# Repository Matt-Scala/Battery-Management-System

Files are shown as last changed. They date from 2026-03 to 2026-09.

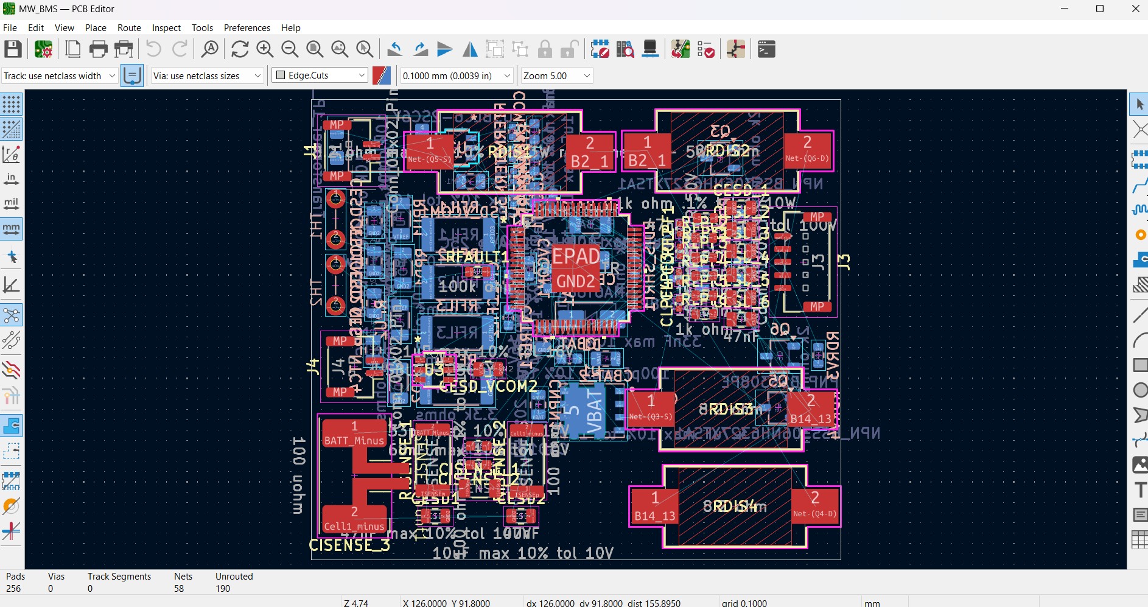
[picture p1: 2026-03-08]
BMS_layout_picture.jpg

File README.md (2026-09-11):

## Members
Matthew Scala, Electrical Engineering
matthewscala3820@vt.edu 

## Mentor
Shane Wyman

## Current Status
Finished

## Project Overview
Create a 4-layer PCB BMS(Battery Management System) with voltage, current, temperature, and fault monitoring. Also, include active cell balancing.

## Educational Value Added

Batteries
Analog routing
SPI communication
Embedded systems
PCB Design 
Electronic Circuit Design

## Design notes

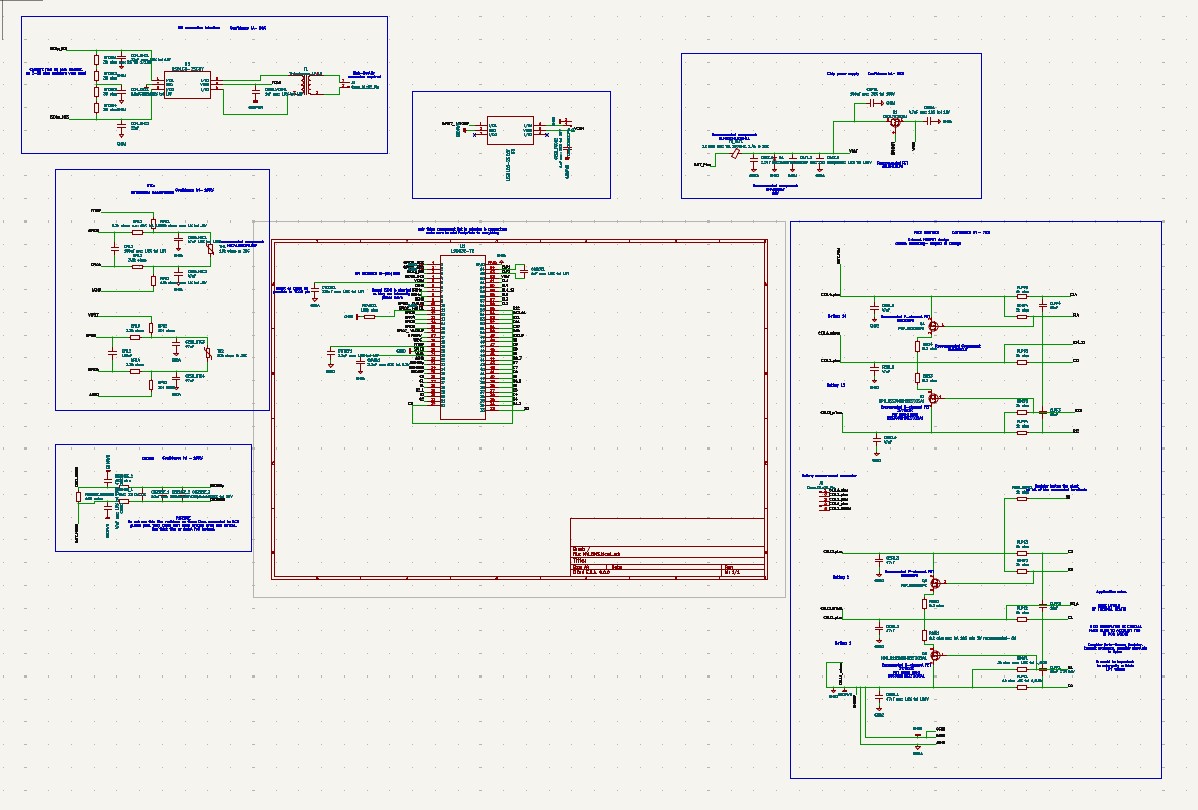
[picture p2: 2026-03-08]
BMS_schematic_picture.jpg

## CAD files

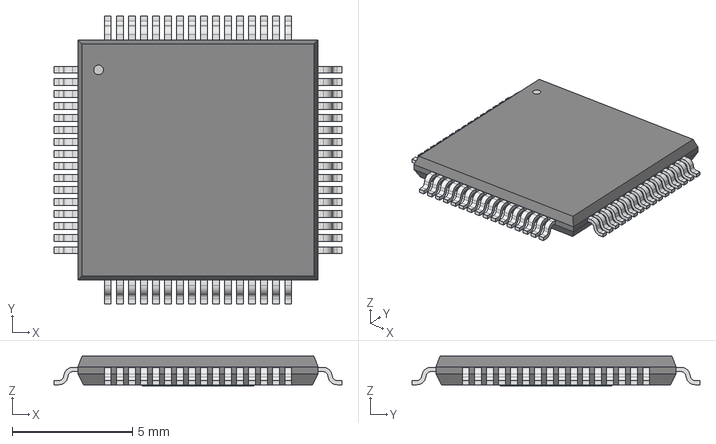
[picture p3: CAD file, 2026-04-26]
CAD_L9963E_TR/TQFP_63E-TR_STM.step
12.0 x 12.0 x 1.25 mm

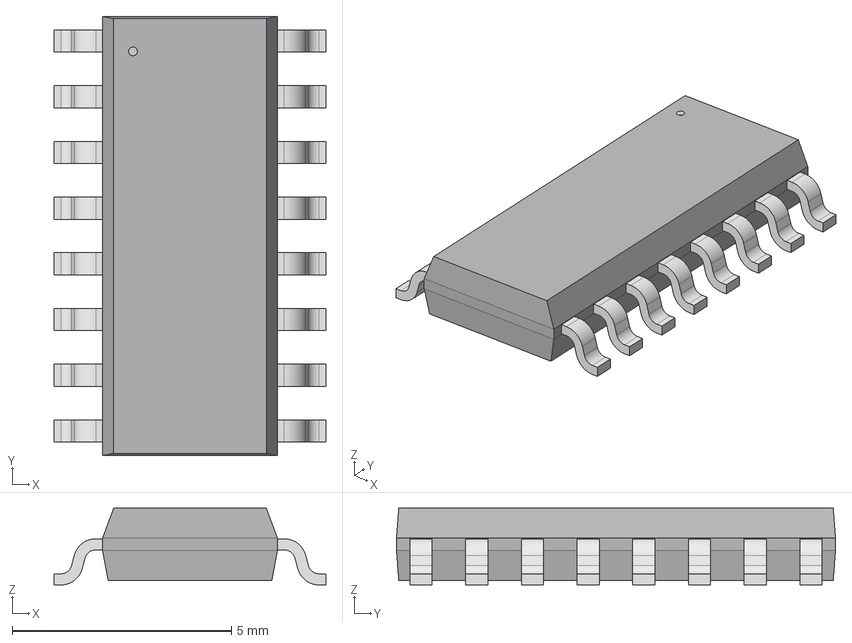
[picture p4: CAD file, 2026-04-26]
CAD_L9963T_TR/SO16N_4X10X1P27_STM.step
6.20 x 10.0 x 1.75 mm

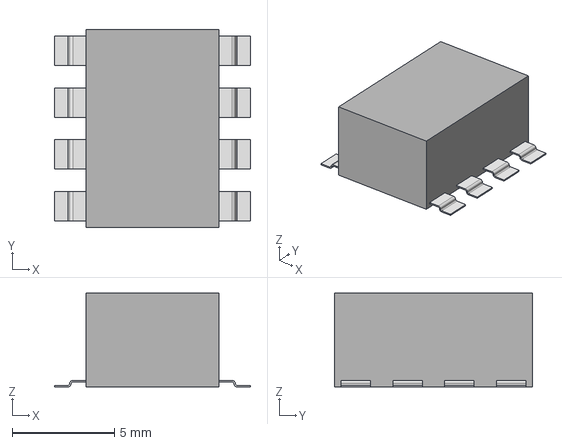
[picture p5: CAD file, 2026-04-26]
CAD_LTV_827S_TA1/LVT-827S_LTO.step
9.60 x 9.68 x 4.60 mm

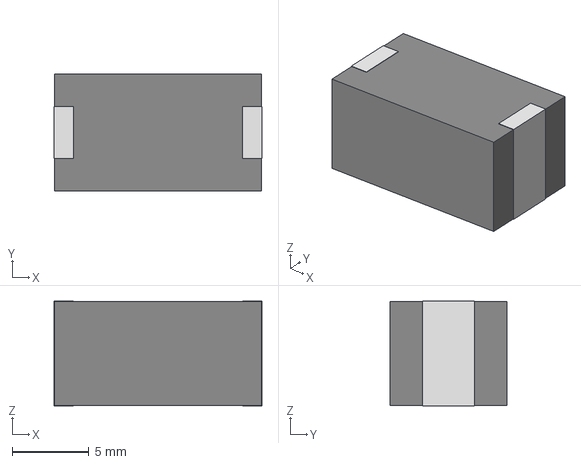
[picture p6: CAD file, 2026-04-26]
CAD_SMW58R2JT/RES_SMF5_TYCO_TYC.step
13.5 x 7.59 x 6.81 mm

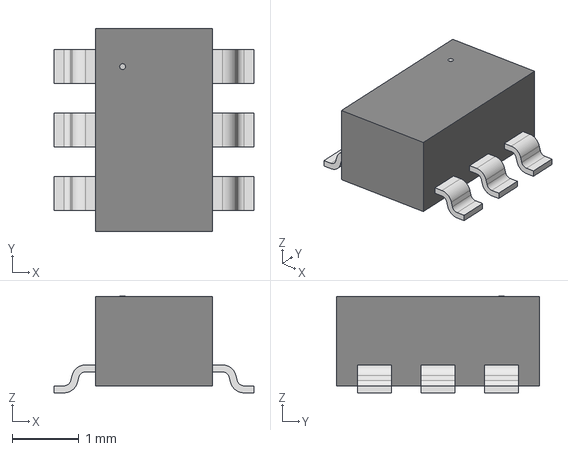
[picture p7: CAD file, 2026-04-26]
CAD_USBLC6_2SC6Y/SOT23-6L_STM.step
3.00 x 3.05 x 1.45 mm

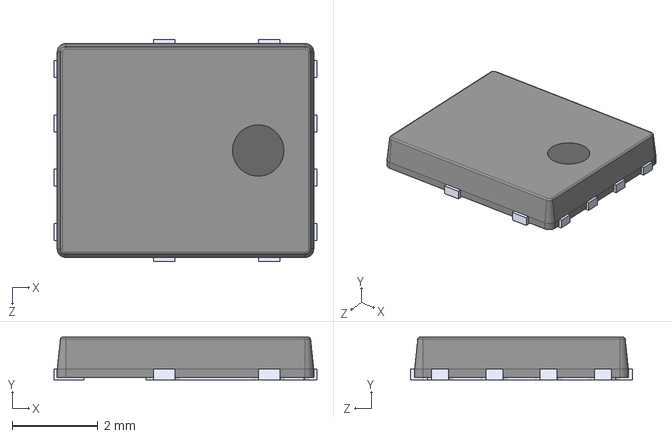
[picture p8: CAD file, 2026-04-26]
STL8N10LF3/STL8N10LF3.step
6.15 x 1.00 x 5.20 mm

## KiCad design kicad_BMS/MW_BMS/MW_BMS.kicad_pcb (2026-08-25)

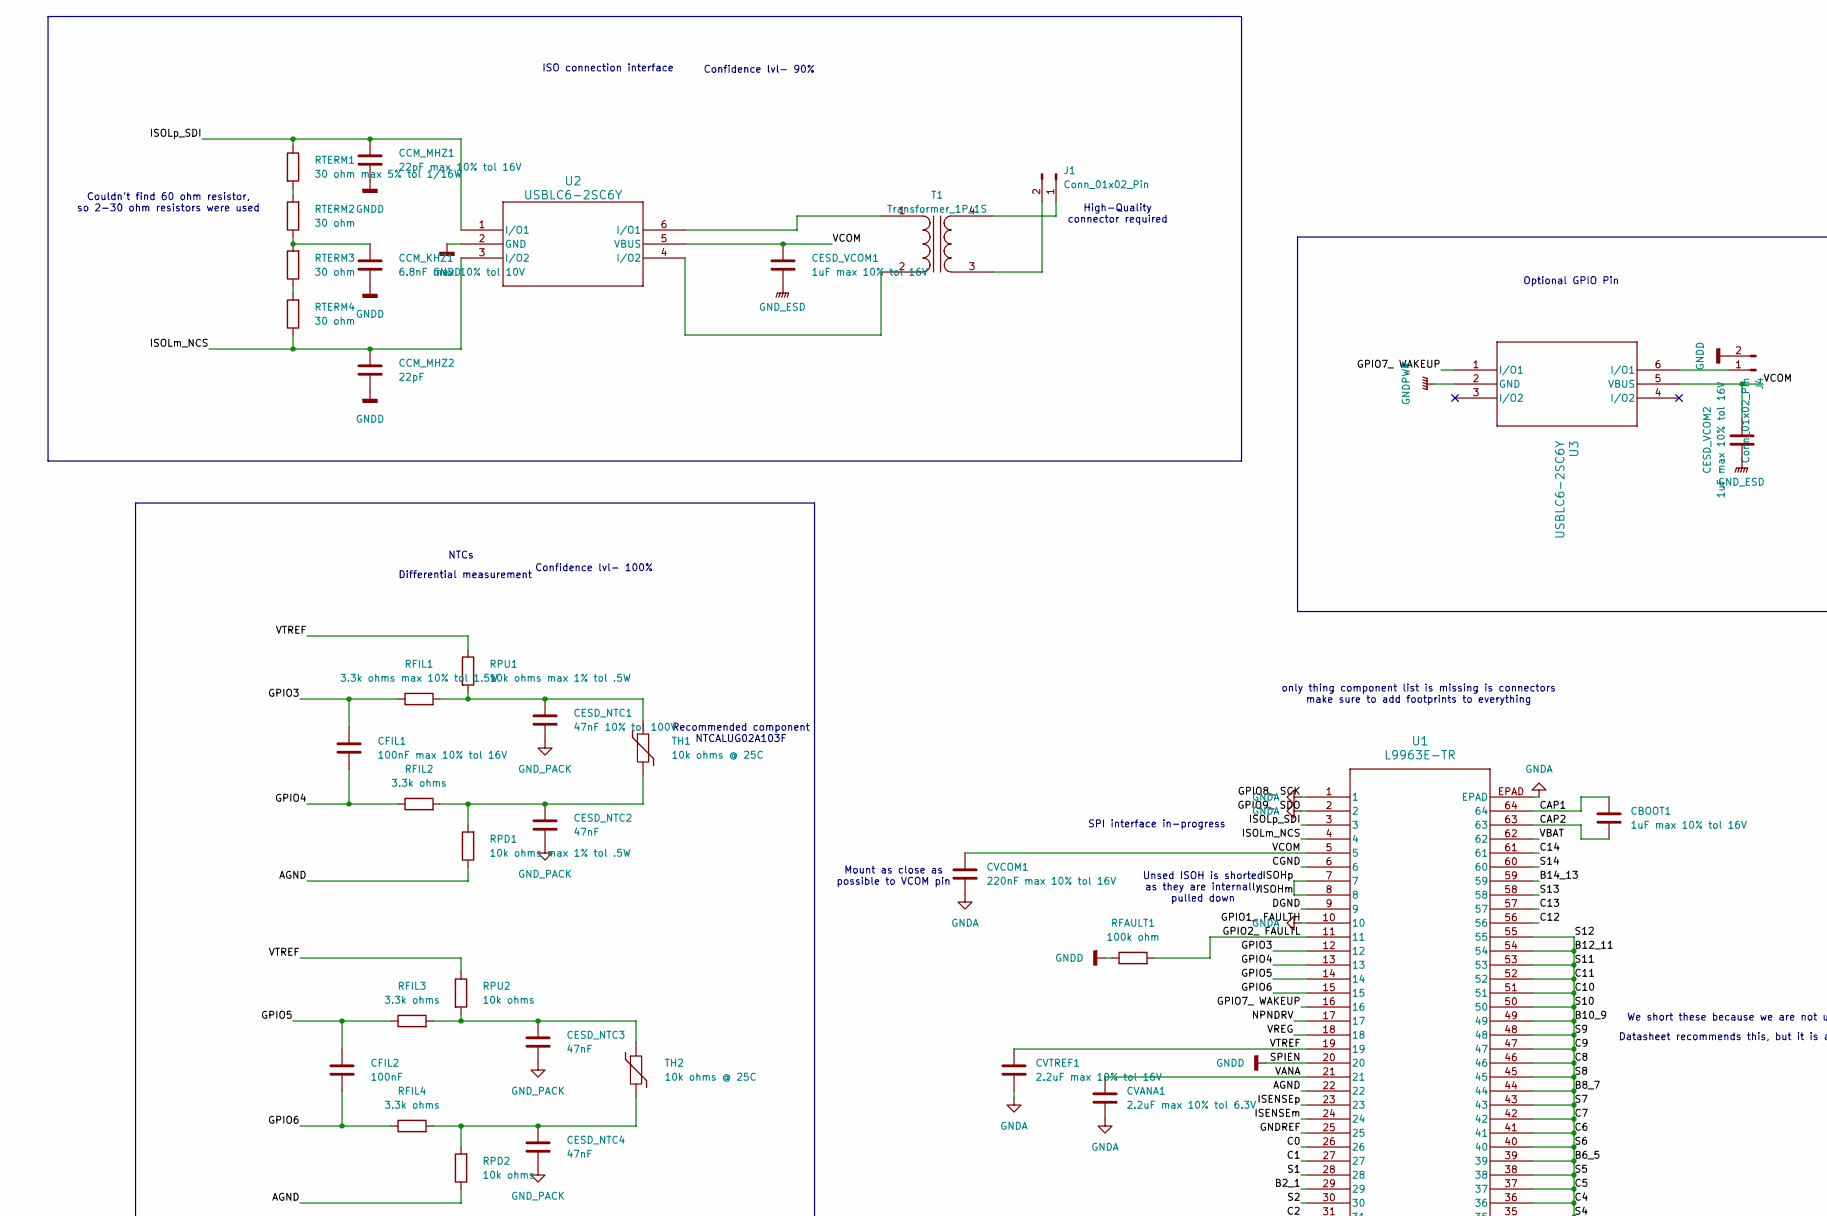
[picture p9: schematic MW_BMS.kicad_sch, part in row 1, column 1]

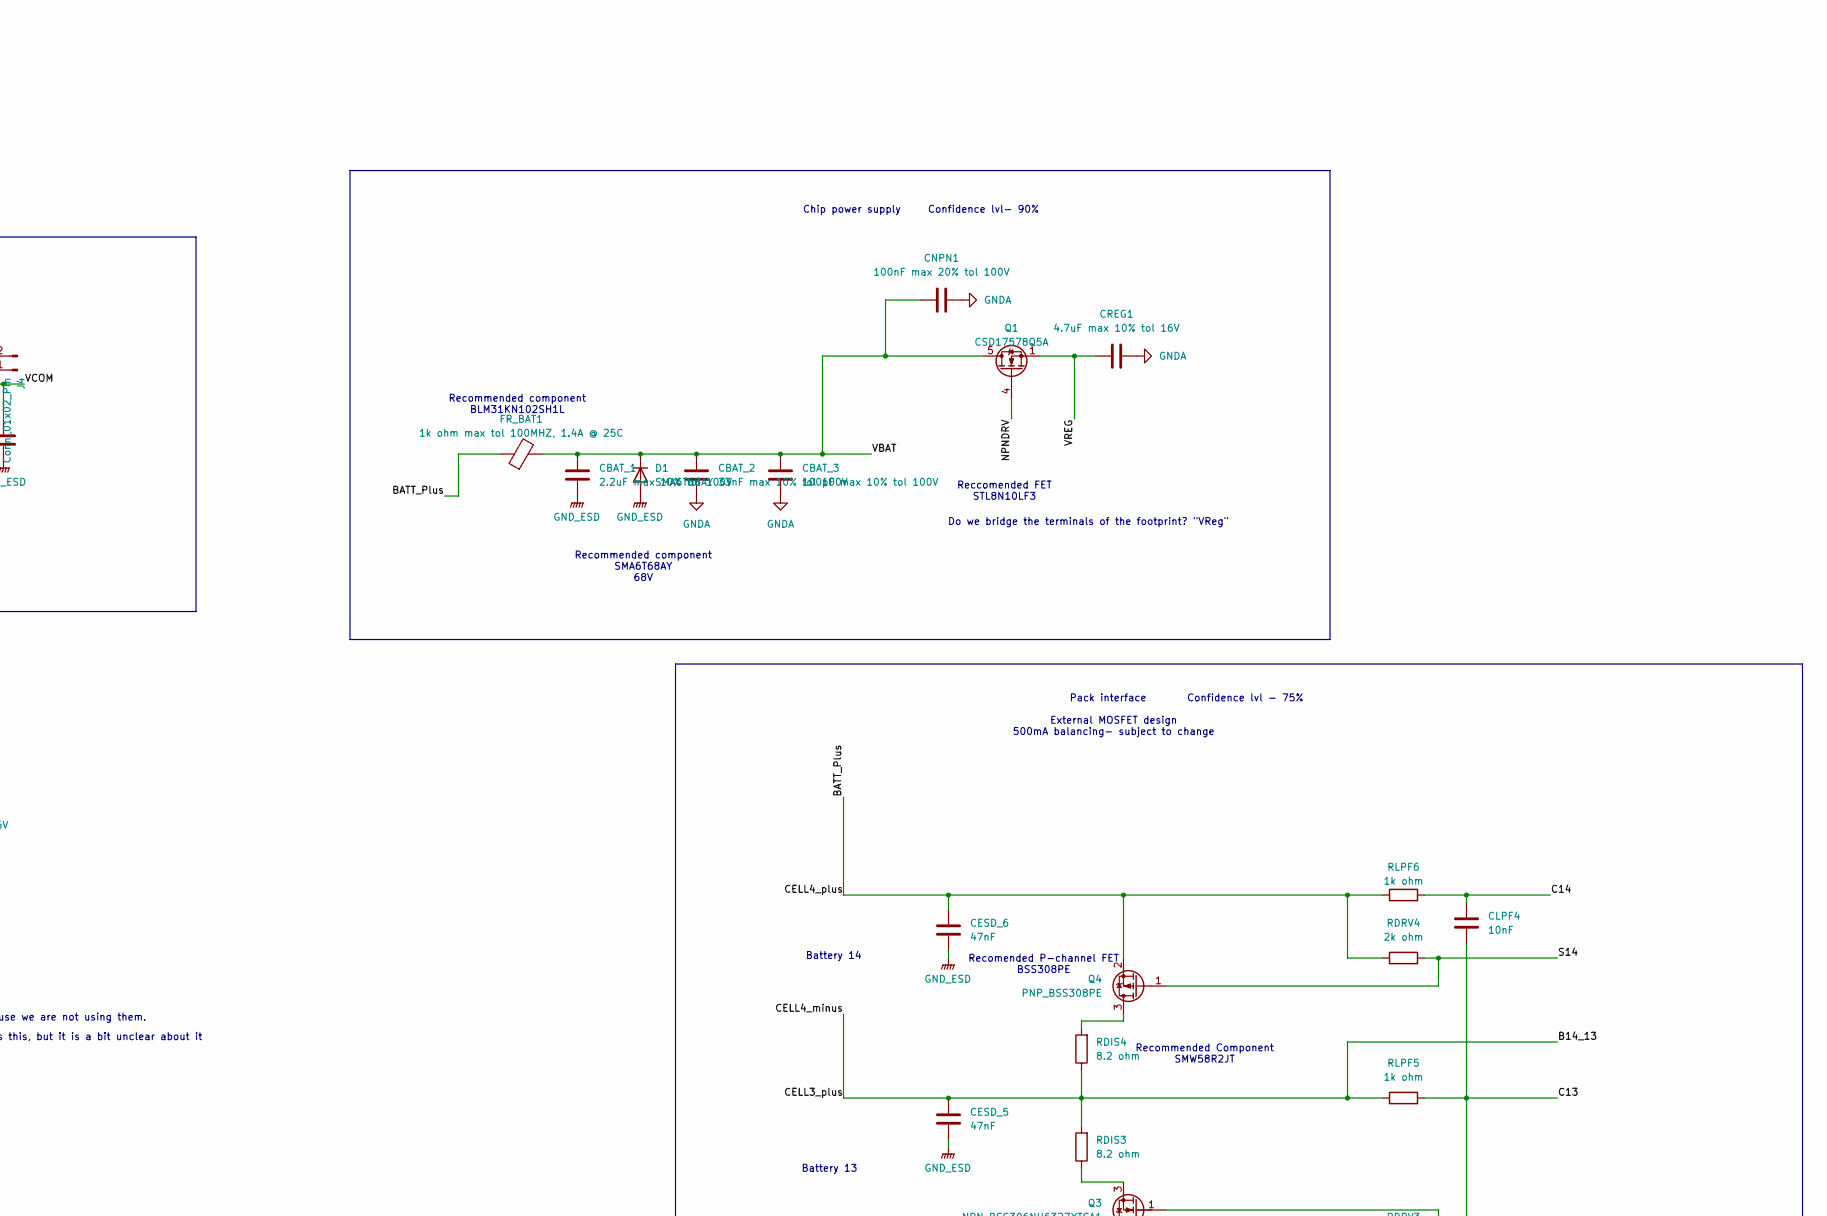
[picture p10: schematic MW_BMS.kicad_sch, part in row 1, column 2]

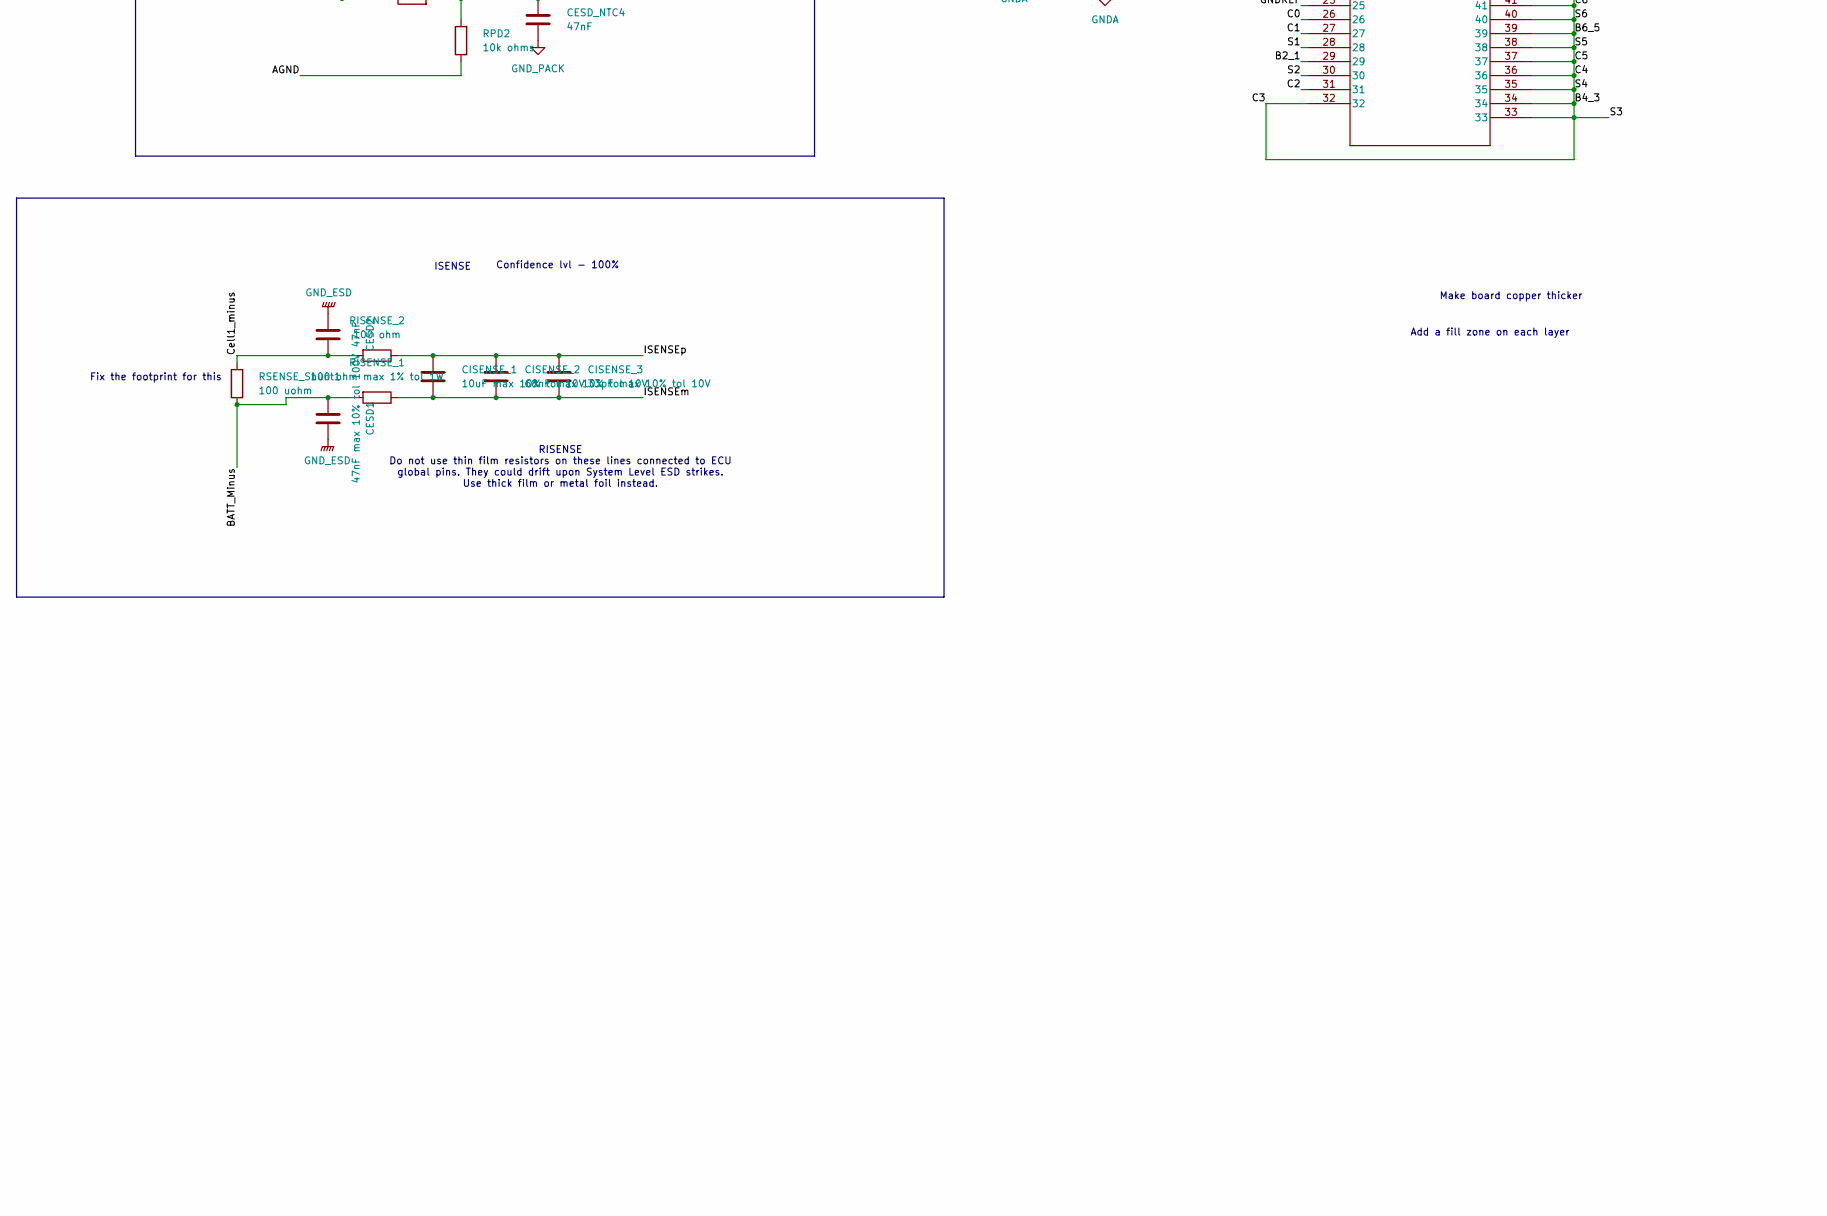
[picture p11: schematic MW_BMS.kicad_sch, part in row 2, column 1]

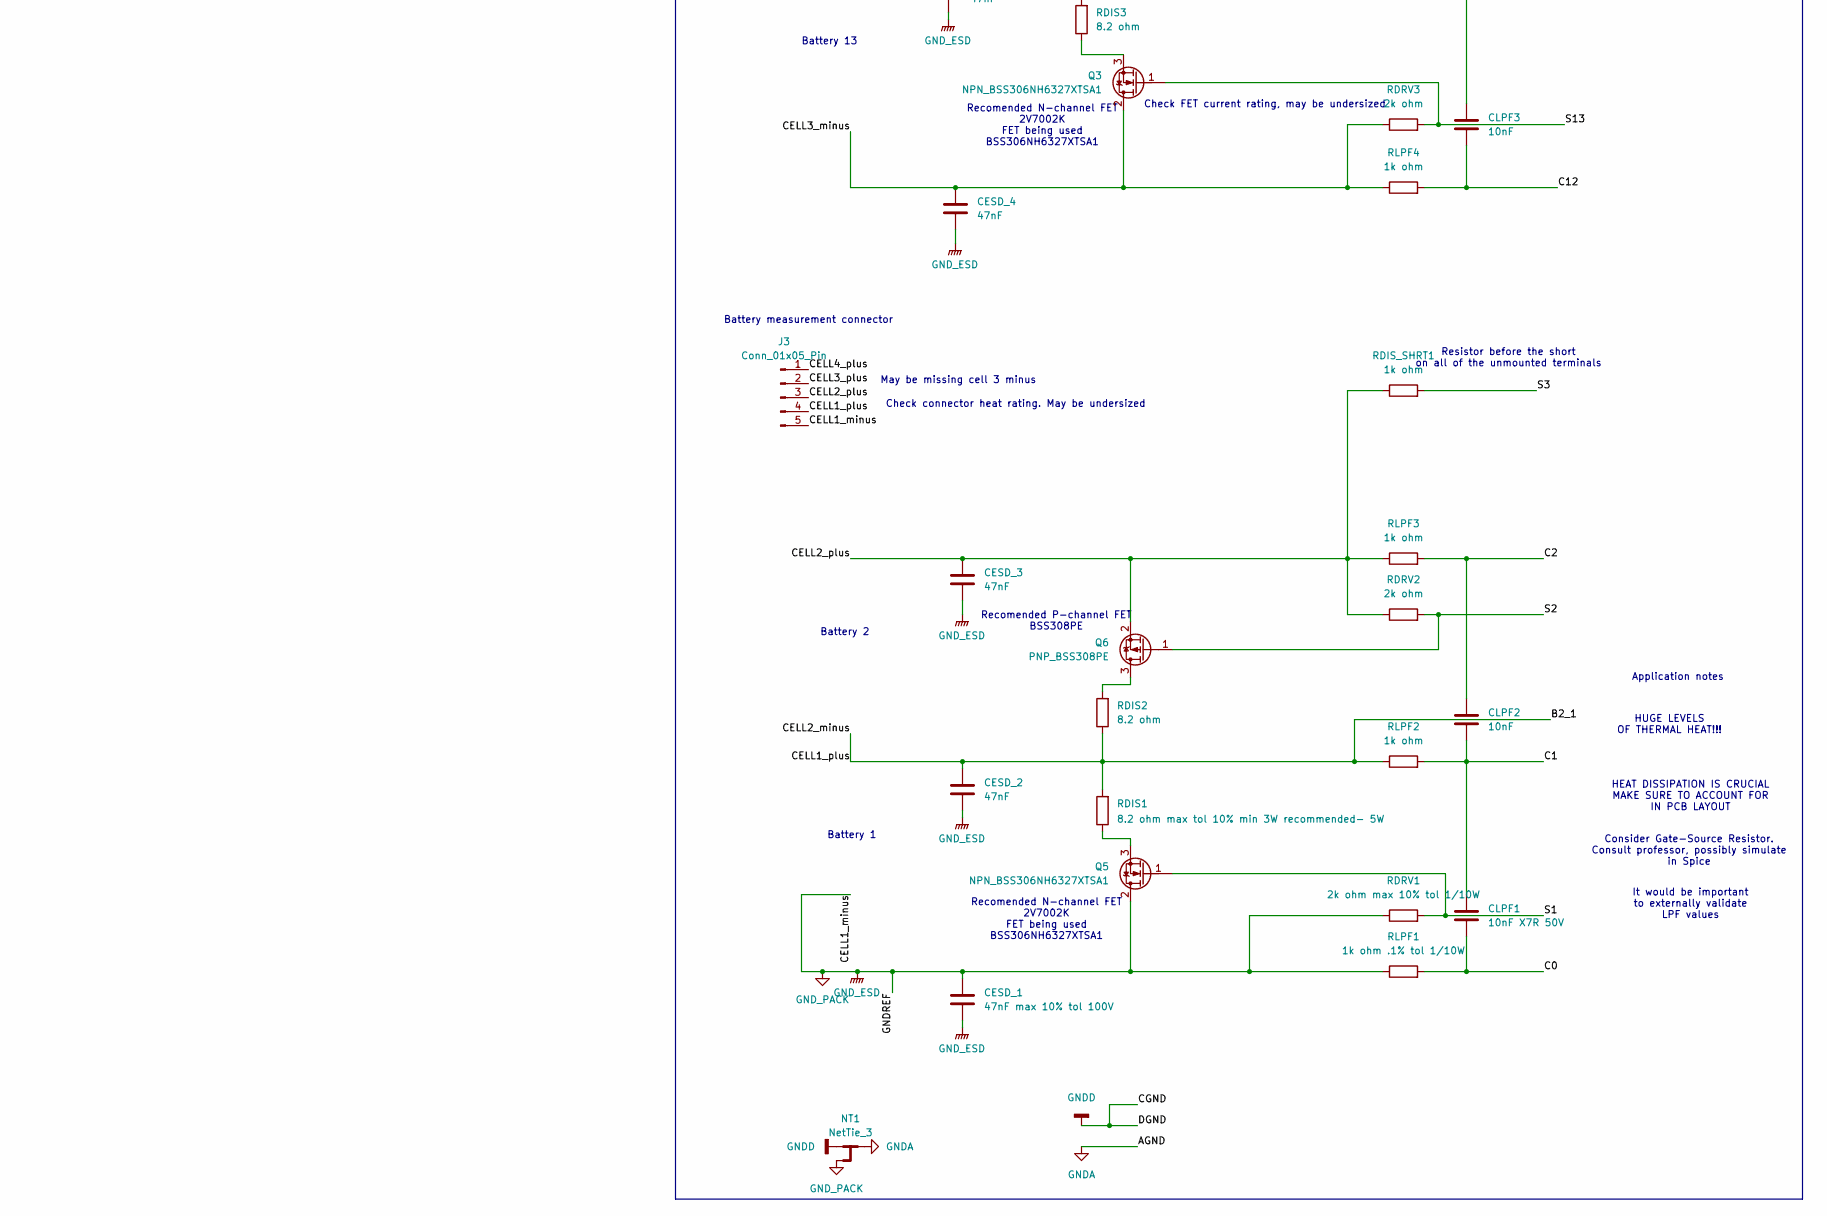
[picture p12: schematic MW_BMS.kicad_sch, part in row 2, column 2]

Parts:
CBAT_1: 2.2uF max 10% tol 100V; C_1206_3216Metric
CBAT_2: 33nF max 10% tol 100V; C_0805_2012Metric
CBAT_3: 100pF max 10% tol 100V; C_0603_1608Metric
CBOOT1: 1uF max 10% tol 16V; C_0603_1608Metric
CCM_KHZ1: 6.8nF max 10% tol 10V; C_0603_1608Metric
CCM_MHZ1: 22pF max 10% tol 16V; C_0603_1608Metric
CCM_MHZ2: 22pF; C_0603_1608Metric
CESD1: 47nF max 10% tol 100V; C_0805_2012Metric
CESD2: 47nF; C_0805_2012Metric
CESD_1: 47nF max 10% tol 100V; C_0805_2012Metric
CESD_2, CESD_3, CESD_4, CESD_5, CESD_6: 47nF; C_0805_2012Metric
CESD_NTC1: 47nF 10% tol 100V; C_0805_2012Metric
CESD_NTC2, CESD_NTC3, CESD_NTC4: 47nF; C_0805_2012Metric
CESD_VCOM1, CESD_VCOM2: 1uF max 10% tol 16V; C_0805_2012Metric
CFIL1: 100nF max 10% tol 16V; C_0603_1608Metric
CFIL2: 100nF; C_0603_1608Metric
CISENSE_1: 10uF max 10% tol 10V; C_1206_3216Metric
CISENSE_2: 68nF max 10% tol 10V; C_0603_1608Metric
CISENSE_3: 33pF max 10% tol 10V; C_0603_1608Metric
CLPF1: 10nF X7R 50V; C_0402_1005Metric
CLPF2, CLPF3, CLPF4: 10nF; C_0402_1005Metric
CNPN1: 100nF max 20% tol 100V; C_0805_2012Metric
CREG1: 4.7uF max 10% tol 16V; C_0805_2012Metric
CVANA1: 2.2uF max 10% tol 6.3V; C_0805_2012Metric
CVCOM1: 220nF max 10% tol 16V; C_0603_1608Metric
CVTREF1: 2.2uF max 10% tol 16V; C_0805_2012Metric
D1: SMA6T68AY; D_SMA
FR_BAT1: 1k ohm max tol 100MHZ, 1.4A @ 25C; R_1206_3216Metric
J1, J4: Conn_01x02_Pin; JST_GH_BM02B-GHS-TBT_1x02-1MP_P1.25mm_Vertical
J3: Conn_01x05_Pin; JST_GH_BM05B-GHS-TBT_1x05-1MP_P1.25mm_Vertical
NT1: NetTie_3; NetTie-3_THT_Pad1.0mm
Q1: CSD17578Q5A; TRANS_STL60P4LLF6
Q3, Q5: NPN_BSS306NH6327XTSA1; TSOT-23
Q4, Q6: PNP_BSS308PE; TSOT-23
RDIS1: 8.2 ohm max tol 10% min 3W recommended- 5W; RES_SMF5_TYCO_TYC
RDIS2, RDIS3, RDIS4: 8.2 ohm; RES_SMF5_TYCO_TYC
RDIS_SHRT1: 1k ohm; R_0603_1608Metric
RDRV1: 2k ohm max 10% tol 1/10W; R_0603_1608Metric
RDRV2, RDRV3, RDRV4: 2k ohm; R_0603_1608Metric
RFAULT1: 100k ohm; R_0603_1608Metric
RFIL1: 3.3k ohms max 10% tol 1.5W; R_2512_6332Metric
RFIL2, RFIL3, RFIL4: 3.3k ohms; R_2512_6332Metric
RISENSE_1: 100 ohm max 1% tol 1W; R_2512_6332Metric
RISENSE_2: 100 ohm; R_2512_6332Metric
RLPF1: 1k ohm .1% tol 1/10W; R_0603_1608Metric
RLPF2, RLPF3, RLPF4, RLPF5, RLPF6: 1k ohm; R_0603_1608Metric
RPD1: 10k ohms max 1% tol .5W; R_1206_3216Metric
RPD2: 10k ohms; R_1206_3216Metric
RPU1: 10k ohms max 1% tol .5W; R_1206_3216Metric
RPU2: 10k ohms; R_1206_3216Metric
RSENSE_Shunt1: 100 uohm; Shunt
RTERM1: 30 ohm max 5% tol 1/16W; R_0402_1005Metric
RTERM2, RTERM3, RTERM4: 30 ohm; R_0402_1005Metric
T1: Transformer_1P_1S; Transformer
TH1, TH2: 10k ohms @ 25C; Thermistor
U1: L9963E-TR; TQFP_63E-TR_STM
U2, U3: USBLC6-2SC6Y; SOT23-6L_STM

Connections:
/B2_1: CESD_2.1, J3.4, RDIS1.2, RDIS2.1, RLPF2.1, U1.29
/B10_9: RDIS_SHRT1.2, U1.32, U1.33, U1.34, U1.35, U1.36, U1.37, U1.38, U1.39, U1.40, U1.41, U1.42, U1.43, U1.44, U1.45, U1.46, U1.47, U1.48, U1.49, U1.50, U1.51, U1.52, U1.53, U1.54, U1.55
/B14_13: CESD_5.1, J3.2, RDIS3.2, RDIS4.1, RLPF5.1, U1.59
/BATT_Minus: CESD1.1, RISENSE_1.2, RSENSE_Shunt1.2
/BATT_Plus: CESD_6.1, FR_BAT1.1, J3.1, Q4.2 (S), RDRV4.1, RLPF6.1
/C0: CLPF1.2, RLPF1.2, U1.26
/C1: CLPF1.1, CLPF2.2, RLPF2.2, U1.27
/C2: CLPF2.1, RLPF3.2, U1.31
/C12: CLPF3.2, RLPF4.2, U1.56
/C13: CLPF3.1, CLPF4.2, RLPF5.2, U1.57
/C14: CLPF4.1, RLPF6.2, U1.61
/CAP1: CBOOT1.1, U1.64
/CAP2: CBOOT1.2, U1.63
/Cell1_minus: CESD2.2, RISENSE_2.2, RSENSE_Shunt1.1
/GPIO2_ FAULTL: RFAULT1.2, U1.11
/GPIO3: CFIL1.1, RFIL1.1, U1.12
/GPIO4: CFIL1.2, RFIL2.1, U1.13
/GPIO5: CFIL2.1, RFIL3.1, U1.14
/GPIO6: CFIL2.2, RFIL4.1, U1.15
/GPIO7_ WAKEUP: U1.16, U3.1 (I/O1)
/ISENSEm: CISENSE_1.1, CISENSE_2.1, CISENSE_3.1, RISENSE_1.1, U1.24
/ISENSEp: CISENSE_1.2, CISENSE_2.2, CISENSE_3.2, RISENSE_2.1, U1.23
/ISOHm: U1.7, U1.8
/ISOLm_NCS: CCM_MHZ2.1, RTERM4.1, U1.4, U2.3 (I/O2)
/ISOLp_SDI: CCM_MHZ1.1, RTERM1.1, U1.3, U2.1 (I/O1)
/NPNDRV: Q1.4 (G), U1.17
/S1: Q5.1 (G), RDRV1.2, U1.28
/S2: Q6.1 (G), RDRV2.2, U1.30
/S13: Q3.1 (G), RDRV3.2, U1.58
/S14: Q4.1 (G), RDRV4.2, U1.60
/VANA: CVANA1.1, U1.21
/VBAT: CBAT_1.1, CBAT_2.1, CBAT_3.1, CNPN1.1, D1.1 (K), FR_BAT1.2, Q1.5 (D), Q1.7, Q1.8, U1.62
/VCOM: CESD_VCOM1.1, CESD_VCOM2.2, CVCOM1.1, U1.5, U2.5 (VBUS), U3.5 (VBUS)
/VREG: CREG1.1, Q1.1 (S), Q1.2 (S), Q1.3 (S), U1.18
/VTREF: CVTREF1.1, RPU1.1, RPU2.1, U1.19
GNDA: CBAT_2.2, CBAT_3.2, CNPN1.2, CREG1.2, CVANA1.2, CVCOM1.2, CVTREF1.2, NT1.2, RPD1.1, RPD2.1, U1.1, U1.2, U1.10, U1.22, U1.EPAD
GNDD: CCM_KHZ1.2, CCM_MHZ1.2, CCM_MHZ2.2, J4.2, NT1.1, RFAULT1.1, U1.6, U1.9, U1.20, U2.2 (GND)
GNDPWR: U3.2 (GND)
GND_ESD: CBAT_1.2, CESD1.2, CESD2.1, CESD_1.1, CESD_1.2, CESD_2.2, CESD_3.2, CESD_4.2, CESD_5.2, CESD_6.2, CESD_NTC1.2, CESD_NTC2.2, CESD_NTC3.2, CESD_NTC4.2, CESD_VCOM1.2, CESD_VCOM2.1, D1.2 (A), J3.5, NT1.3, Q5.2 (D), RDRV1.1, RLPF1.1, U1.25
unnamed: CCM_KHZ1.1, RTERM2.1, RTERM3.2
unnamed: CESD_NTC1.1, RFIL1.2, RPU1.2, TH1.1
unnamed: CESD_NTC2.1, RFIL2.2, RPD1.2, TH1.2
unnamed: CESD_NTC3.1, RFIL3.2, RPU2.2, TH2.1
unnamed: CESD_NTC4.1, RFIL4.2, RPD2.2, TH2.2
unnamed: J1.1, T1.4 (SB)
unnamed: J1.2, T1.3 (SA)
unnamed: J4.1, U3.6 (I/O1)
unnamed: Q3.3 (S), RDIS3.1
unnamed: Q4.3 (D), RDIS4.2
unnamed: Q5.3 (S), RDIS1.1
unnamed: Q6.3 (D), RDIS2.2
unnamed: RTERM1.2, RTERM2.2
unnamed: RTERM3.1, RTERM4.2
unnamed: T1.1 (AA), U2.6 (I/O1)
unnamed: T1.2 (AB), U2.4 (I/O2)

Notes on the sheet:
ISENSE
Unsed ISOH is shorted as they are internally pulled down
Confidence lvl- 100%
Datasheet recommends this, but it is a bit unclear about it
Couldn't find 60 ohm resistor, so 2-30 ohm resistors were used
Confidence lvl- 90%
We short these because we are not using them.
Recommended Component SMW58R2JT
It would be important to externally validate LPF values
Resistor before the short on all of the unmounted terminals
RISENSE Do not use thin film resistors on these lines connected to ECU global pins. They could drift upon System Level ESD strikes. Use thick film or metal foil instead.
ISO connection interface
Pack interface
Do we bridge the terminals of the footprint? "VReg"
Confidence lvl - 100%
Reccomended FET STL8N10LF3
Recommended component SMA6T68AY 68V
Battery 1
Recomended N-channel FET 2V7002K FET being used BSS306NH6327XTSA1
Check connector heat rating. May be undersized
Battery 13
HEAT DISSIPATION IS CRUCIAL MAKE SURE TO ACCOUNT FOR IN PCB LAYOUT
Confidence lvl - 75%
Application notes
Differential measurement
Recomended P-channel FET BSS308PE
SPI interface in-progress
Add a fill zone on each layer
Mount as close as possible to VCOM pin
Make board copper thicker
High-Quality connector required
Check FET current rating, may be undersized
Optional GPIO Pin
May be missing cell 3 minus
Recommended component NTCALUG02A103F
Chip power supply
Battery 2
Recommended component BLM31KN102SH1L
Battery 14
only thing component list is missing is connectors make sure to add footprints to everything

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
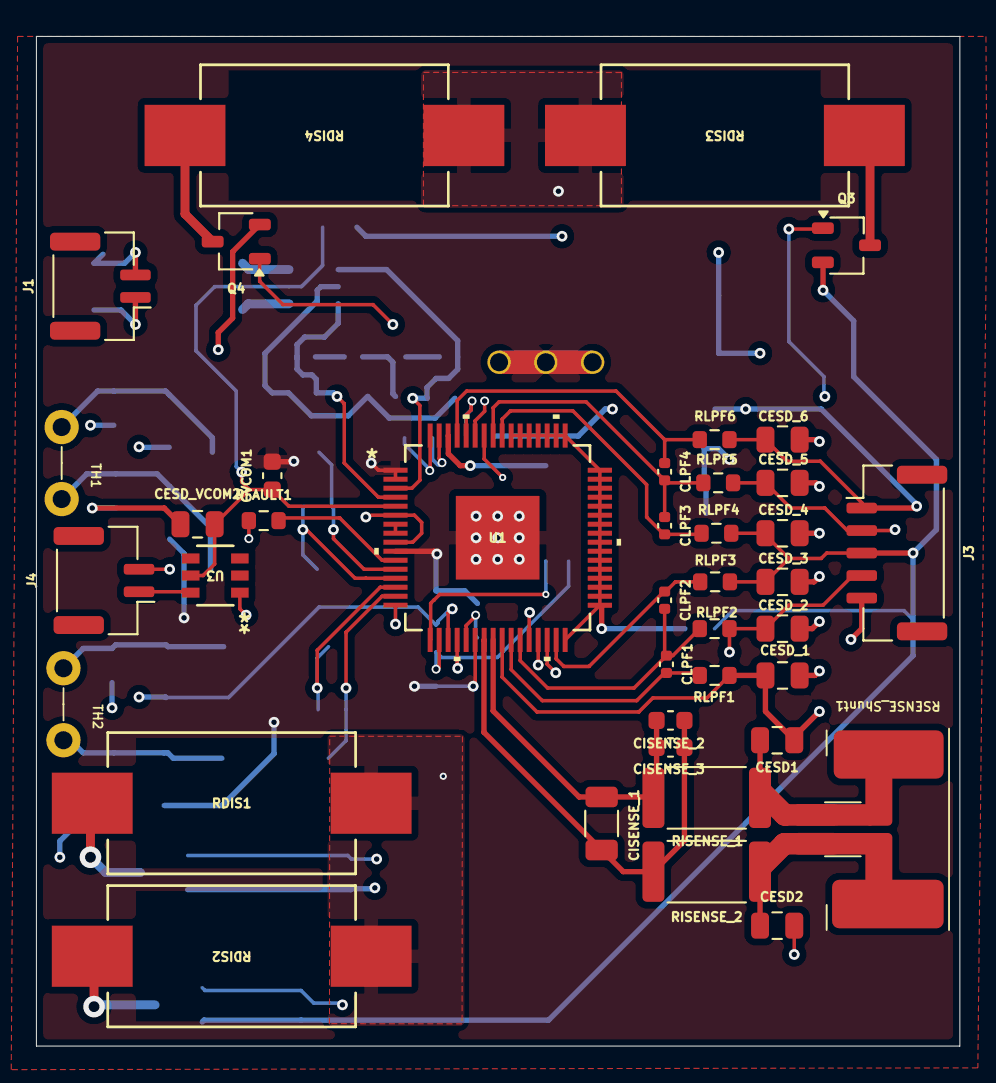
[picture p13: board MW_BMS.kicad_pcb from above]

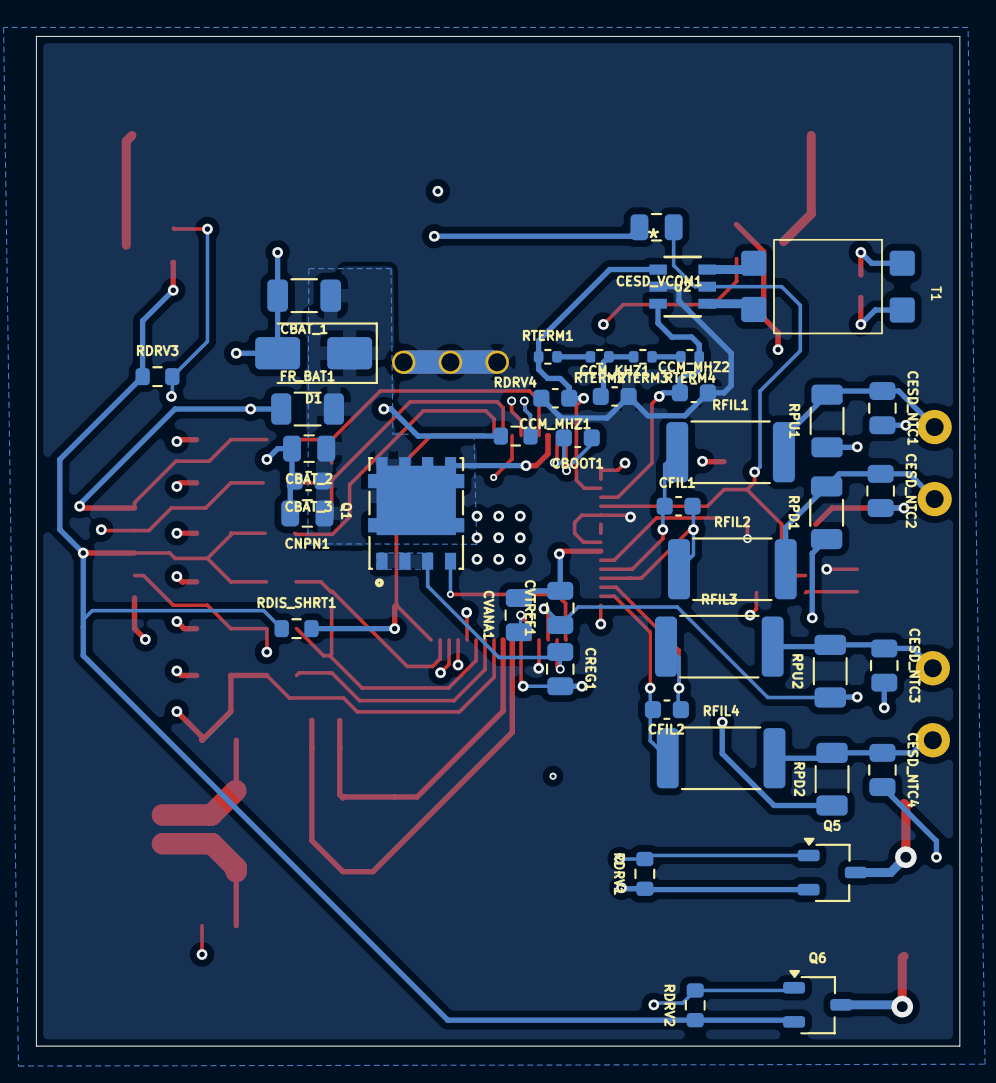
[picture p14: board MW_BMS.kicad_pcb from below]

Board: 4 copper layers, 51.3 x 56.1 mm, 83 parts (42 on the bottom side), 55 nets.

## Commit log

2026-04-26 more files
    [LVT-827S_LTO.step, RES_SMF5_TYCO_TYC.step, SO16N_4X10X1P27_STM.step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]
2026-04-27 more_improvements
    just need ground planes, and to make a decision about cell3_minus
    [MW_BMS.kicad_pcb, MW_BMS.kicad_sch]
2026-05-19 fixed spi
    [MW_BMS.kicad_pcb]
2026-05-31 ground connected
    [MW_BMS.kicad_pcb]
2026-05-31 closed kicad on laptop
2026-08-24 pad gnd
    [MW_BMS.kicad_pcb]
2026-08-25 fixing DRC errors
    [MW_BMS.kicad_pcb]
